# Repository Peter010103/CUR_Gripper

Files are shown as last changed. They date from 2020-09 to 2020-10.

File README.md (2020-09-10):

# CUR_Gripper
Cambridge University Robotics > Robocup Rescue > GripperV4

- URDF file produced using https://github.com/yanshil/Fusion2PyBullet
- Visualisation graphs produced using https://github.com/yanshil/Joint2Graphviz

The Fusion scripts from the above links are in the scripts folder for convenience.

# Hardware Overview
- 6 x ROBOTIS AX-12A actuators used for Gripper, Roll & Yaw Axis & Pitch Axis(?)
- 3D printed in PETG (STL files in [assets](catkin_ws/src/gripperv4/assets))

Follows a common 4-bar linkage (parallelogram) mechanism for gripping action. The wrist axes are designed to be able to rotate a full 360 degrees (must ensure long enough wires are used !)

<p align="center">
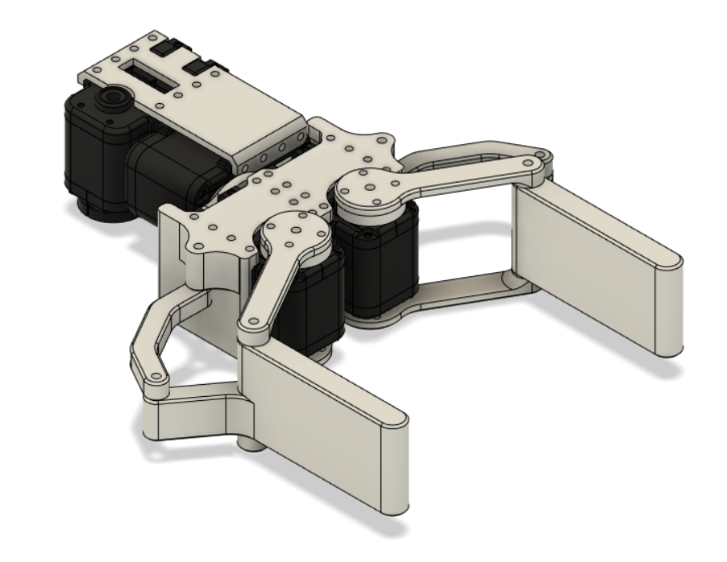
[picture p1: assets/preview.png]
  
</p>

# URDF Layout
<p align="center">
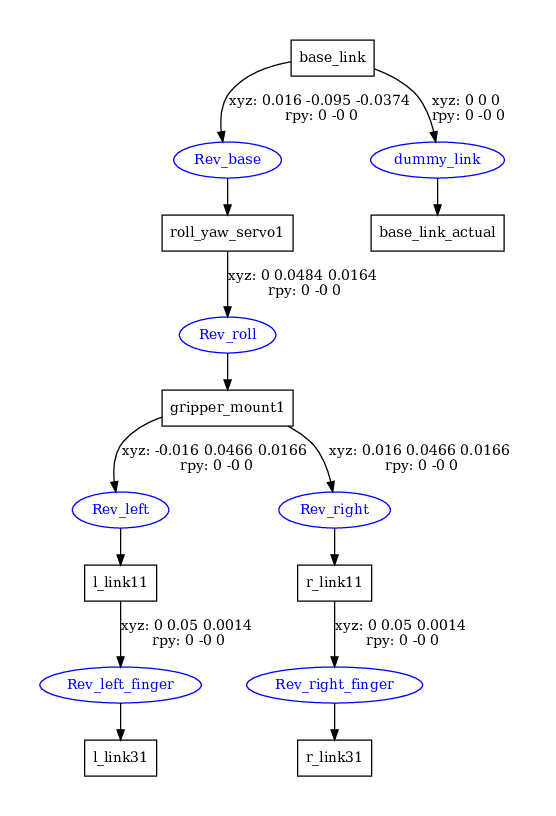
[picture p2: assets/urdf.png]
  
</p>

To conform with the URDF format, some components were removed to make the tree 'open-loop' in RViz. Dependent joints between the servo arm (link1) and the finger (link3) were added ([dependent_joints.yaml](catkin_ws/src/gripperv4/config/dependent_joints.yaml)) instead to mimic the motion of the parallelogram mechanism.

# RViz Simulation
<p align="center">
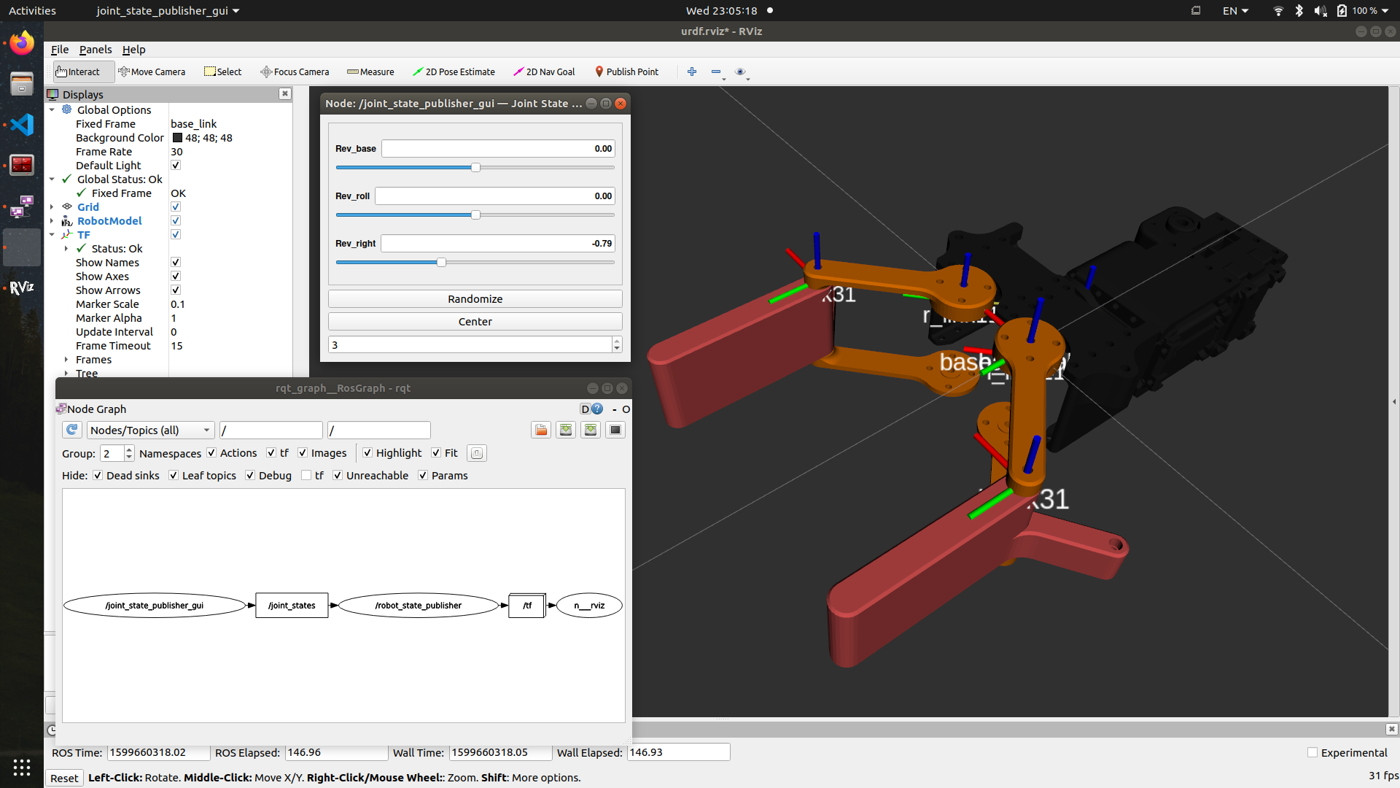
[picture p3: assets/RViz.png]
  
</p>

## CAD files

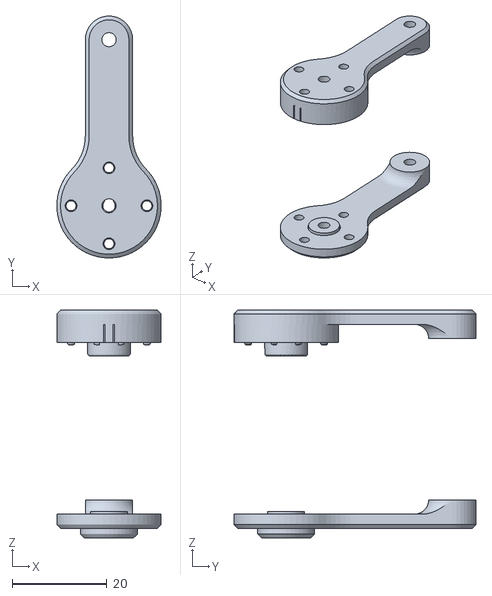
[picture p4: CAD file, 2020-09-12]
assets/gripperv4_urdf/meshes/r_link11.stl
22.0 x 51.0 x 48.0

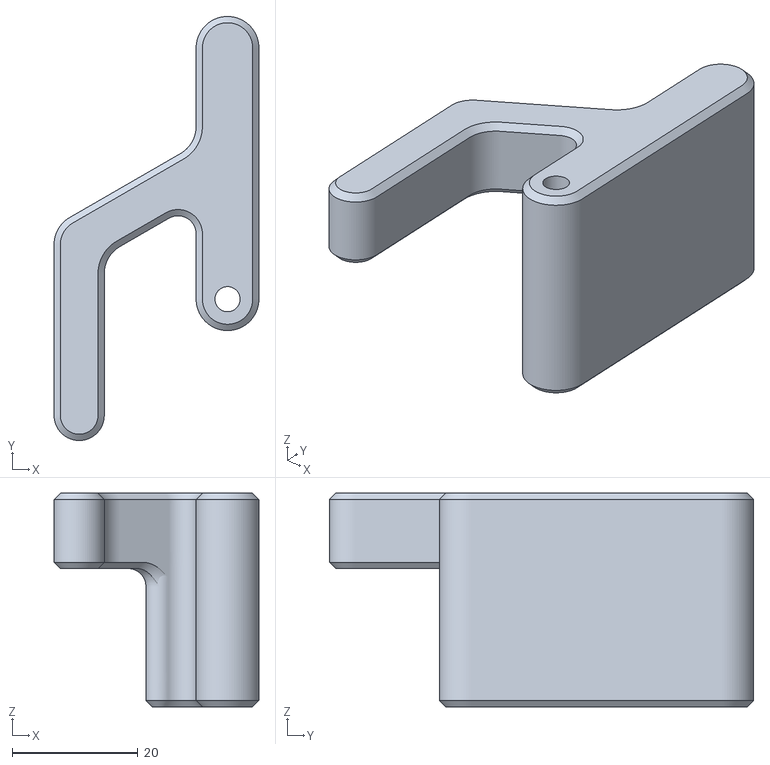
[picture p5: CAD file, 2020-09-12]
assets/STL/l_link3.stl
32.6 x 67.5 x 34.0

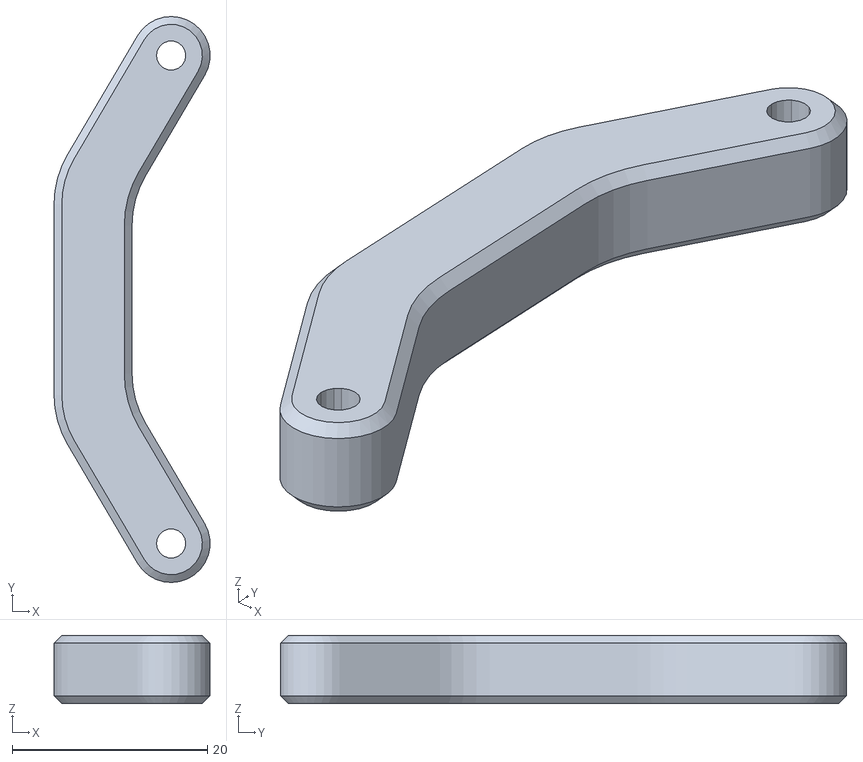
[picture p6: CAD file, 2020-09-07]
gripperv4_description/meshes/L_Link2_1.stl
16.0 x 58.0 x 7.00

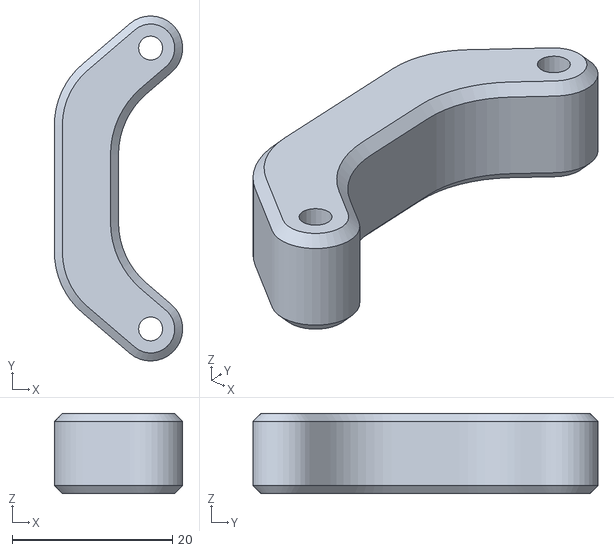
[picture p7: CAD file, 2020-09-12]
assets/gripperv4_urdf/meshes/l_link21.stl
16.0 x 43.0 x 10.0

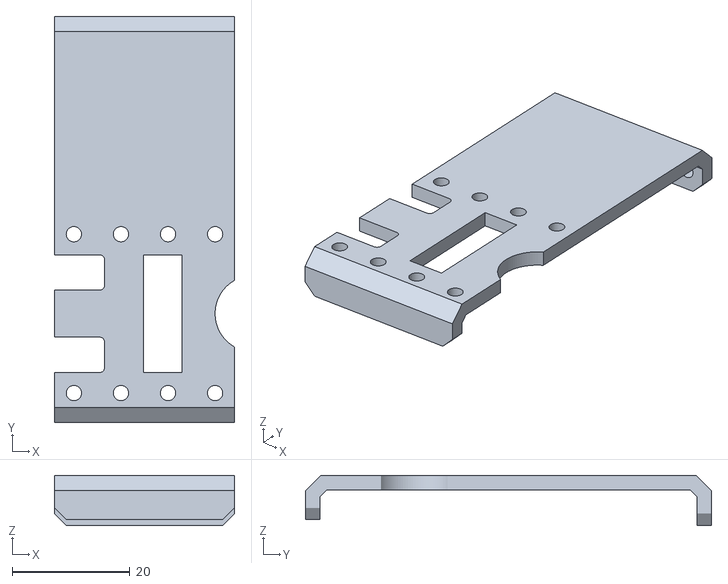
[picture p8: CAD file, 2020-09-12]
assets/STL/roll_yaw_mount1.stl
30.6 x 69.0 x 8.50

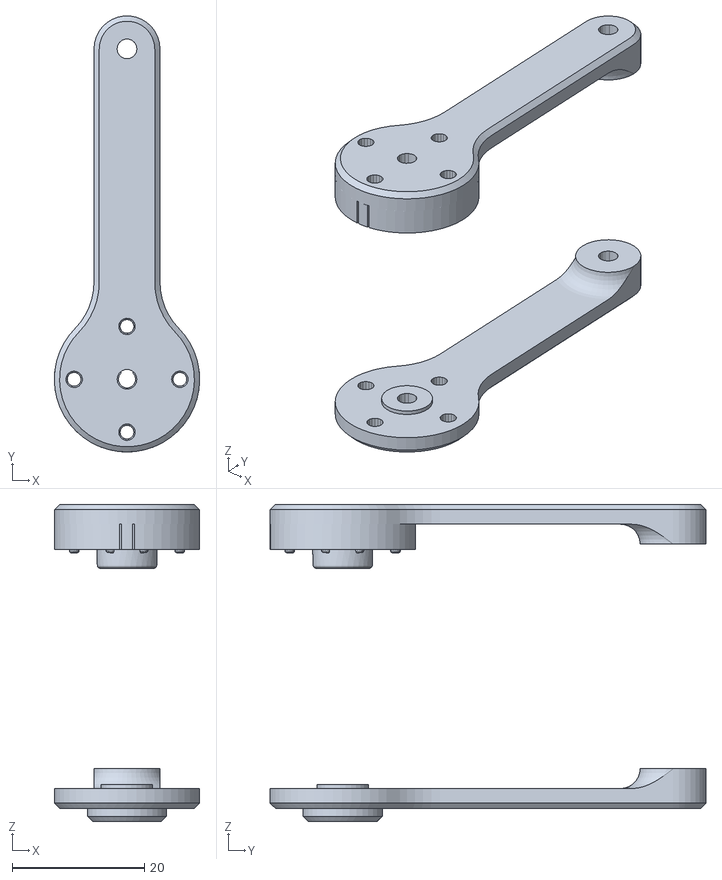
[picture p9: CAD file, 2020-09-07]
gripperv4_description/meshes/R_Link1_1.stl
22.0 x 66.0 x 48.0

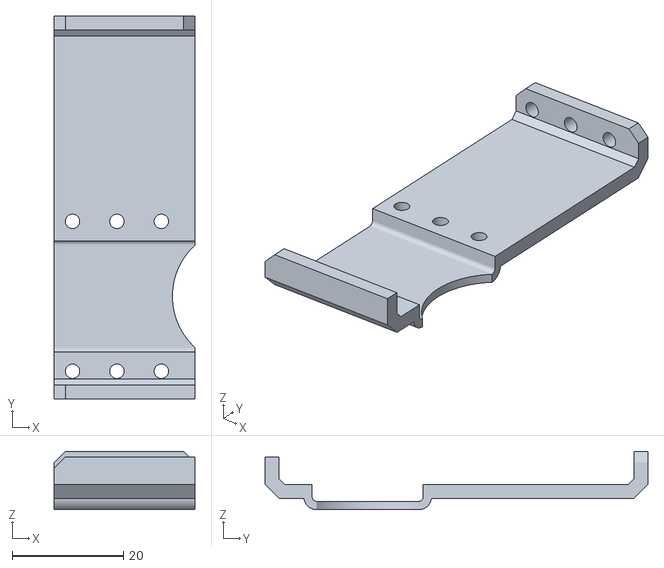
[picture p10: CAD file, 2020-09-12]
assets/STL/roll_yaw_mount2.stl
25.3 x 69.0 x 10.5

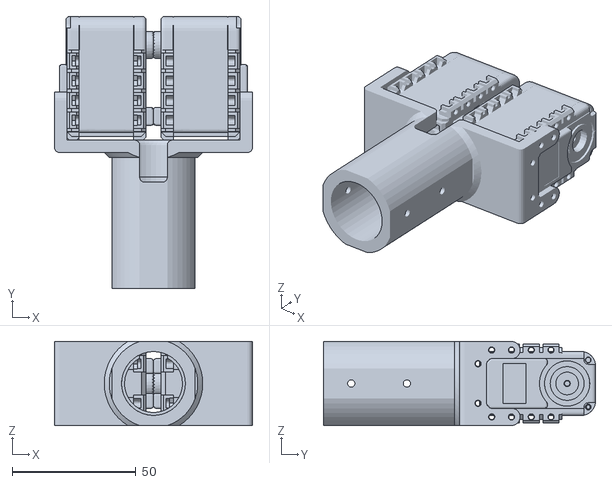
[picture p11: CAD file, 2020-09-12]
catkin_ws/src/gripperv4/assets/base_link.stl
80.0 x 110.0 x 34.0

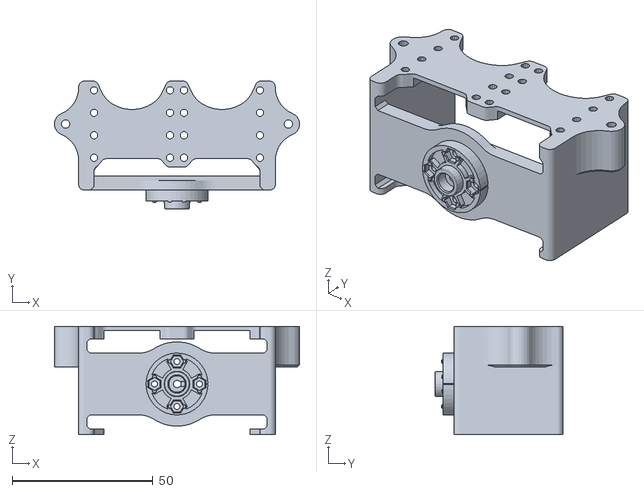
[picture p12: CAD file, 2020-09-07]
gripperv4_description/meshes/Mount1_1.stl
87.2 x 45.5 x 38.5

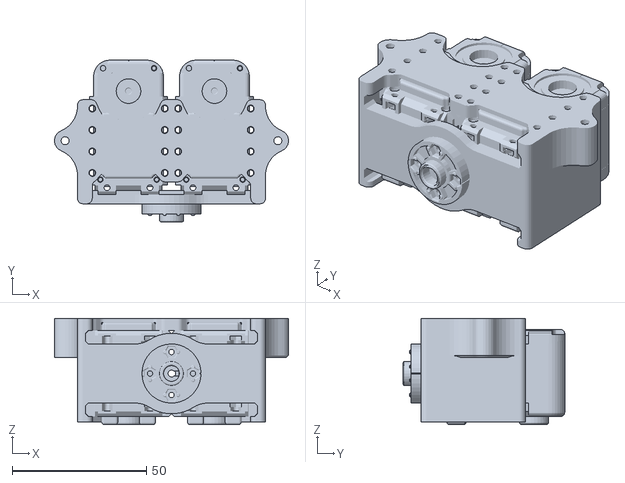
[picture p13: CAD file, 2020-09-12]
catkin_ws/src/gripperv4/assets/gripper_mount1.stl
87.2 x 60.2 x 39.5

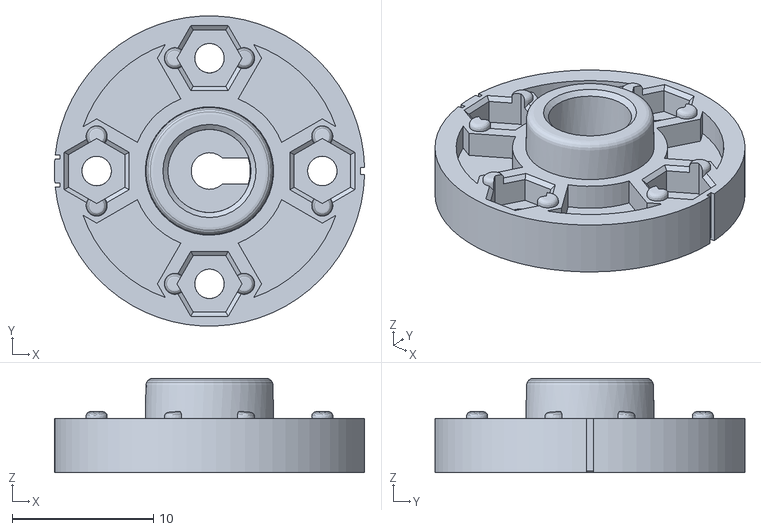
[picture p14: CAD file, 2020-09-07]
gripperv4_description/meshes/base_link.stl
22.0 x 22.0 x 6.70

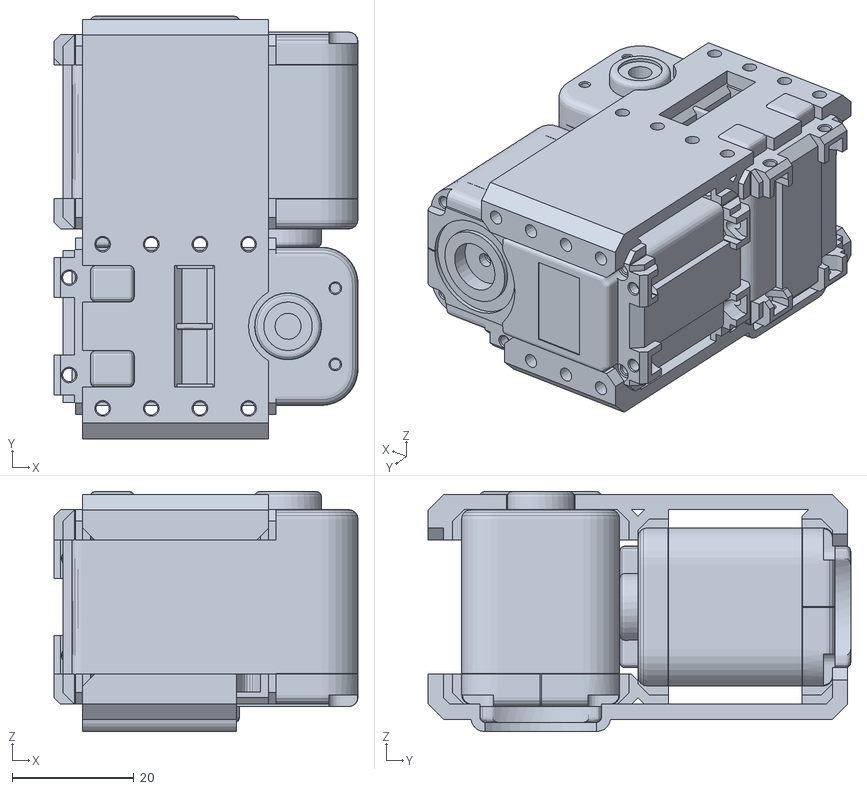
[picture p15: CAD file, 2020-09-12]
assets/gripperv4_urdf/meshes/roll_yaw_servo1.stl
50.0 x 69.5 x 39.5

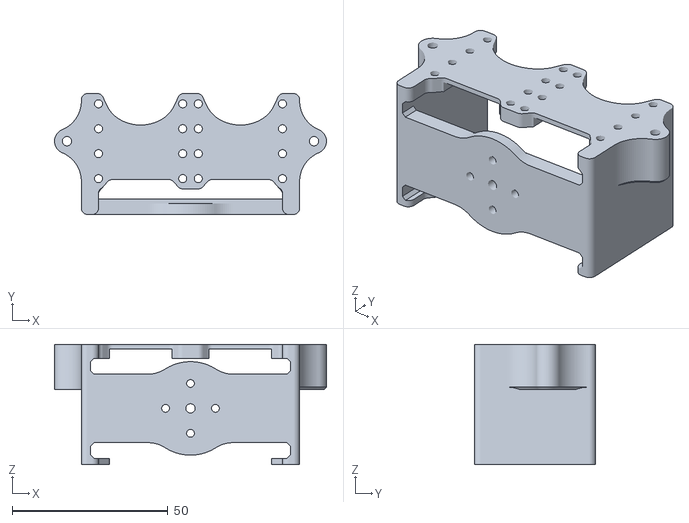
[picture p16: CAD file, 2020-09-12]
assets/STL/gripper_mount.stl
87.2 x 38.8 x 38.5

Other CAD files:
catkin_ws/src/gripperv4/assets/l_link11.stl
assets/gripperv4_urdf/meshes/r_link21.stl
assets/STL/r_link2.stl
archive/gripperv4/meshes/base_link.stl
archive/gripperv4/meshes/gripper_mount1.stl
archive/gripperv4/meshes/l_link11.stl
archive/gripperv4/meshes/l_link31.stl
archive/gripperv4/meshes/l_servo1.stl
archive/gripperv4/meshes/r_link11.stl
archive/gripperv4/meshes/r_link21.stl
archive/gripperv4/meshes/r_link31.stl
archive/gripperv4/meshes/r_servo1.stl
archive/gripperv4/meshes/roll2yaw_mount1.stl
archive/gripperv4/meshes/roll_servo1.stl
archive/gripperv4/meshes/yaw_servo1.stl
archive/gripperv4_description/meshes/L_Body_1.stl
archive/gripperv4_description/meshes/L_Link1_1.stl
archive/gripperv4_description/meshes/L_Link3_1.stl
archive/gripperv4_description/meshes/Mount2_1.stl
archive/gripperv4_description/meshes/R_Body_1.stl
archive/gripperv4_description/meshes/R_Link2_1.stl
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

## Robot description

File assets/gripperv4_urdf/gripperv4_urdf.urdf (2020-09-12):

<?xml version="1.0" ?>
<robot name="gripperv4_urdf">

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

<link name="base_link">
  <inertial>
    <origin rpy="0 0 0" xyz="2.1845298122770527e-09 -0.09133155977238687 0.020875468296511556"/>
    <mass value="0.9490572232520995"/>
    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
  </inertial>
  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
</link>

<link name="pitch_mount1">
  <inertial>
    <origin rpy="0 0 0" xyz="-0.035381834259905855 0.022820220401733052 -0.002066974265373219"/>
    <mass value="0.08039663104912372"/>
    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
  </inertial>
  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
</link>

<link name="roll_yaw_servo1">
  <inertial>
    <origin rpy="0 0 0" xyz="-0.01326814497835662 0.016285248127358473 -0.018675533177308117"/>
    <mass value="0.6469480906726006"/>
    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
  </inertial>
  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
</link>

<link name="gripper_mount1">
  <inertial>
    <origin rpy="0 0 0" xyz="-4.6437802248194846e-05 0.03250667598502349 0.0006919679540483038"/>
    <mass value="0.6706735500880907"/>
    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
  </inertial>
  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
</link>

<link name="r_link11">
  <inertial>
    <origin rpy="0 0 0" xyz="9.352171946239163e-08 0.004350148087522404 -0.003859751771437374"/>
    <mass value="0.01374798583124482"/>
    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
  </inertial>
  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
</link>

<link name="r_finger1">
  <inertial>
    <origin rpy="0 0 0" xyz="0.004967469486381864 0.01646646237182653 -0.015003164576295747"/>
    <mass value="0.023712538812289255"/>
    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
  </inertial>
  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
</link>

<link name="l_link11">
  <inertial>
    <origin rpy="0 0 0" xyz="9.506871556999585e-08 0.004350155042648504 -0.0038597459406704976"/>
    <mass value="0.013747989643093032"/>
    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
  </inertial>
  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
</link>

<link name="l_finger1">
  <inertial>
    <origin rpy="0 0 0" xyz="-0.004967279382909973 0.01646646237182653 -0.015003164576295747"/>
    <mass value="0.023712538812289255"/>
    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
  </inertial>
  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
</link>

<link name="l_link21">
  <inertial>
    <origin rpy="0 0 0" xyz="-0.005348338062402411 0.017499999999999932 -0.004999999999999647"/>
    <mass value="0.00386409068463368"/>
    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
  </inertial>
  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
</link>

<link name="r_link21">
  <inertial>
    <origin rpy="0 0 0" xyz="0.005348528165873591 0.017499999999999932 -0.004999999999999647"/>
    <mass value="0.0038640906846336806"/>
    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
  </inertial>
  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
</link>

<joint name="Rev27" type="continuous">
  <origin rpy="0 0 0" xyz="0.0354 -0.063124 0.021"/>
  <parent link="base_link"/>
  <child link="pitch_mount1"/>
  <axis xyz="1.0 0.0 0.0"/>
</joint>
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

<joint name="Rev28" type="continuous">
  <origin rpy="0 0 0" xyz="-0.035383 0.063124 0.0184"/>
  <parent link="pitch_mount1"/>
  <child link="roll_yaw_servo1"/>
  <axis xyz="0.0 0.0 1.0"/>
</joint>
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

<joint name="Rev29" type="continuous">
  <origin rpy="0 0 0" xyz="0.0 0.0484 -0.0184"/>
  <parent link="roll_yaw_servo1"/>
  <child link="gripper_mount1"/>
  <axis xyz="0.0 1.0 -0.0"/>
</joint>
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

<joint name="Rev30" type="continuous">
  <origin rpy="0 0 0" xyz="0.016 0.0466 0.0164"/>
  <parent link="gripper_mount1"/>
  <child link="r_link11"/>
  <axis xyz="0.0 -0.0 1.0"/>
</joint>
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

<joint name="Rev31" type="continuous">
  <origin rpy="0 0 0" xyz="0.0 0.035 0.0016"/>
  <parent link="r_link11"/>
  <child link="r_finger1"/>
  <axis xyz="0.0 -0.0 1.0"/>
</joint>
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

<joint name="Rev32" type="continuous">
  <origin rpy="0 0 0" xyz="-0.016 0.0466 0.0164"/>
  <parent link="gripper_mount1"/>
  <child link="l_link11"/>
  <axis xyz="0.0 -0.0 1.0"/>
</joint>
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

<joint name="Rev33" type="continuous">
  <origin rpy="0 0 0" xyz="0.0 0.035 0.0016"/>
  <parent link="l_link11"/>
  <child link="l_finger1"/>
  <axis xyz="-0.0 0.0 -1.0"/>
</joint>
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

<joint name="Rev34" type="continuous">
  <origin rpy="0 0 0" xyz="-0.039617 0.0281 0.006"/>
  <parent link="gripper_mount1"/>
  <child link="l_link21"/>
  <axis xyz="-0.0 0.0 -1.0"/>
</joint>
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

<joint name="Rev35" type="continuous">
  <origin rpy="0 0 0" xyz="0.039617 0.0281 0.006"/>
  <parent link="gripper_mount1"/>
  <child link="r_link21"/>
  <axis xyz="0.0 -0.0 1.0"/>
</joint>
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

</robot>

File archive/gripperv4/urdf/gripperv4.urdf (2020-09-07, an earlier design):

<?xml version="1.0" ?>
<robot name="gripperv4">

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

<link name="base_link">
  <inertial>
    <origin rpy="0 0 0" xyz="0.015992436485837883 -0.0949999999742469 -0.040090057637020185"/>
    <mass value="0.009061016616131982"/>
    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
  </inertial>
  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
</link>

<link name="yaw_servo1">
  <inertial>
    <origin rpy="0 0 0" xyz="-0.013167494315320315 -4.684638372969008e-05 0.01584835755541894"/>
    <mass value="0.3184697824599338"/>
    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
  </inertial>
  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
</link>

<link name="roll2yaw_mount1">
  <inertial>
    <origin rpy="0 0 0" xyz="0.014120331710048785 0.03382582487425398 -0.01421655548476504"/>
    <mass value="0.010008525752734407"/>
    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
  </inertial>
  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
</link>

<link name="roll_servo1">
  <inertial>
    <origin rpy="0 0 0" xyz="-0.009967494315320308 -0.014898357555418865 -0.01549684638372982"/>
    <mass value="0.3184697824599338"/>
    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
  </inertial>
  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
</link>

<link name="gripper_mount1">
  <inertial>
    <origin rpy="0 0 0" xyz="-4.055486153327348e-05 0.015016957245028106 0.0033366712510858668"/>
    <mass value="0.03378268770833562"/>
    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
  </inertial>
  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
</link>

<link name="l_servo1">
  <inertial>
    <origin rpy="0 0 0" xyz="0.013453153616270093 0.0013325056846796753 -0.015248357555418993"/>
    <mass value="0.3184697824599338"/>
    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
  </inertial>
  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
</link>

<link name="r_servo1">
  <inertial>
    <origin rpy="0 0 0" xyz="-0.013546846383729903 0.0013325056846796805 -0.015248357555418993"/>
    <mass value="0.3184697824599338"/>
    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
  </inertial>
  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
</link>

<link name="l_link11">
  <inertial>
    <origin rpy="0 0 0" xyz="1.5906387325074444e-11 0.007497428337157438 -0.004836993401442812"/>
    <mass value="0.014672073181914151"/>
    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
  </inertial>
  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
</link>

<link name="l_link31">
  <inertial>
    <origin rpy="0 0 0" xyz="-0.0017956453296221562 0.02496942356962671 -0.018242185156636687"/>
    <mass value="0.027635011745384516"/>
    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
  </inertial>
  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
</link>

<link name="l_link31">
  <inertial>
    <origin rpy="0 0 0" xyz="0.021821354670377845 0.043469423569626714 0.0007578148433633122"/>
    <mass value="0.027635011745384516"/>
    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
  </inertial>
  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
</link>

<link name="l_link21">
  <inertial>
    <origin rpy="0 0 0" xyz="-0.005239897396468952 0.024999999999999953 -0.0034999999999999996"/>
    <mass value="0.0034055466614027626"/>
    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
  </inertial>
  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
</link>

<link name="r_link11">
  <inertial>
    <origin rpy="0 0 0" xyz="-1.4336560688610334e-09 0.007497418801402903 -0.004836999106063676"/>
    <mass value="0.014672069251285016"/>
    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
  </inertial>
  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
</link>

<link name="r_link31">
  <inertial>
    <origin rpy="0 0 0" xyz="0.0017956453296221475 0.024969423569626725 -0.018242185156636687"/>
    <mass value="0.027635011745384488"/>
    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
  </inertial>
  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
</link>

<link name="r_link31">
  <inertial>
    <origin rpy="0 0 0" xyz="-0.02182135467037785 0.04346942356962673 0.0007578148433633122"/>
    <mass value="0.027635011745384488"/>
    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
  </inertial>
  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
</link>

<link name="r_link21">
  <inertial>
    <origin rpy="0 0 0" xyz="0.005239897396468955 0.024999999999999953 -0.0034999999999999996"/>
    <mass value="0.0034055466614027626"/>
    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
  </inertial>
  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
</link>

<joint name="Rev88" type="continuous">
  <origin rpy="0 0 0" xyz="0.016 -0.095 -0.0374"/>
  <parent link="base_link"/>
  <child link="yaw_servo1"/>
  <axis xyz="0.0 0.0 1.0"/>
</joint>
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

<joint name="Rigid89" type="fixed">
  <origin rpy="0 0 0" xyz="-0.0338 -0.01545 0.03185"/>
  <parent link="yaw_servo1"/>
  <child link="roll2yaw_mount1"/>
</joint>

<joint name="Rigid90" type="fixed">
  <origin rpy="0 0 0" xyz="0.0306 0.0629 0.0"/>
  <parent link="roll2yaw_mount1"/>
  <child link="roll_servo1"/>
</joint>

<joint name="Rev91" type="continuous">
  <origin rpy="0 0 0" xyz="0.0032 0.00095 -0.01545"/>
  <parent link="roll_servo1"/>
  <child link="gripper_mount1"/>
  <axis xyz="-0.0 -1.0 0.0"/>
</joint>
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

<joint name="Rigid92" type="fixed">
  <origin rpy="0 0 0" xyz="-0.0295 0.0321 0.016"/>
  <parent link="gripper_mount1"/>
  <child link="l_servo1"/>
</joint>

<joint name="Rigid93" type="fixed">
  <origin rpy="0 0 0" xyz="0.0295 0.0321 0.016"/>
  <parent link="gripper_mount1"/>
  <child link="r_servo1"/>
</joint>

<joint name="Rev94" type="continuous">
  <origin rpy="0 0 0" xyz="0.0135 0.0145 0.0006"/>
  <parent link="l_servo1"/>
  <child link="l_link11"/>
  <axis xyz="0.0 0.0 1.0"/>
</joint>
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

<joint name="Rev95" type="continuous">
  <origin rpy="0 0 0" xyz="-0.023617 0.0315 -0.0176"/>
  <parent link="l_link11"/>
  <child link="l_link31"/>
  <axis xyz="0.0 0.0 1.0"/>
</joint>
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

<joint name="Rev96" type="continuous">
  <origin rpy="0 0 0" xyz="0.0 0.05 -0.007"/>
  <parent link="l_link21"/>
  <child link="l_link31"/>
  <axis xyz="0.0 0.0 -1.0"/>
</joint>
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

<joint name="Rev97" type="continuous">
  <origin rpy="0 0 0" xyz="-0.039617 0.0281 0.006"/>
  <parent link="gripper_mount1"/>
  <child link="l_link21"/>
  <axis xyz="0.0 0.0 -1.0"/>
</joint>
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

<joint name="Rev98" type="continuous">
  <origin rpy="0 0 0" xyz="-0.0135 0.0145 0.0006"/>
  <parent link="r_servo1"/>
  <child link="r_link11"/>
  <axis xyz="0.0 0.0 1.0"/>
</joint>
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

<joint name="Rev99" type="continuous">
  <origin rpy="0 0 0" xyz="0.023617 0.0315 -0.0176"/>
  <parent link="r_link11"/>
  <child link="r_link31"/>
  <axis xyz="0.0 0.0 -1.0"/>
</joint>
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

<joint name="Rev100" type="continuous">
  <origin rpy="0 0 0" xyz="0.0 0.05 -0.007"/>
  <parent link="r_link21"/>
  <child link="r_link31"/>
  <axis xyz="0.0 0.0 1.0"/>
</joint>
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

<joint name="Rev101" type="continuous">
  <origin rpy="0 0 0" xyz="0.039617 0.0281 0.006"/>
  <parent link="gripper_mount1"/>
  <child link="r_link21"/>
  <axis xyz="0.0 0.0 1.0"/>
</joint>
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

</robot>

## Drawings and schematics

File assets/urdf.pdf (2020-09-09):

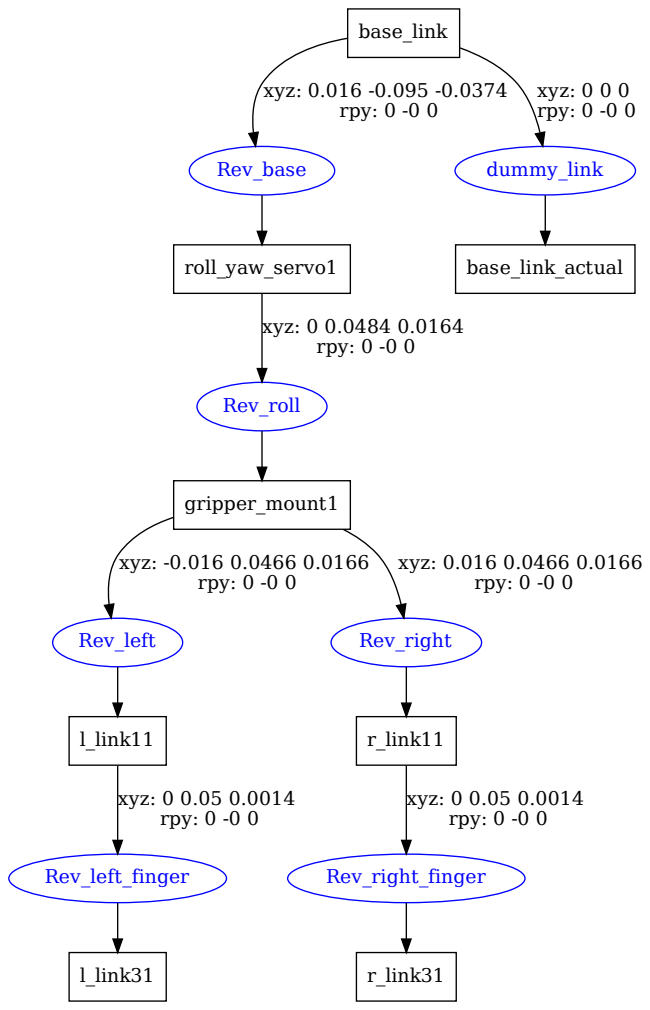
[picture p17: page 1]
base_link; Rev_base; xyz: 0.016 -0.095 -0.0374 rpy: 0 -0 0; dummy_link; xyz: 0 0 0 rpy: 0 -0 0; roll_yaw_servo1; Rev_roll; xyz: 0 0.0484 0.0164 rpy: 0 -0 0; gripper_mount1; Rev_left; xyz: -0.016 0.0466 0.0166 rpy: 0 -0 0; Rev_right; xyz: 0.016 0.0466 0.0166 rpy: 0 -0 0; l_link11; Rev_left_finger; xyz: 0 0.05 0.0014 rpy: 0 -0 0; l_link31; r_link11; Rev_right_finger; r_link31; base_link_actual

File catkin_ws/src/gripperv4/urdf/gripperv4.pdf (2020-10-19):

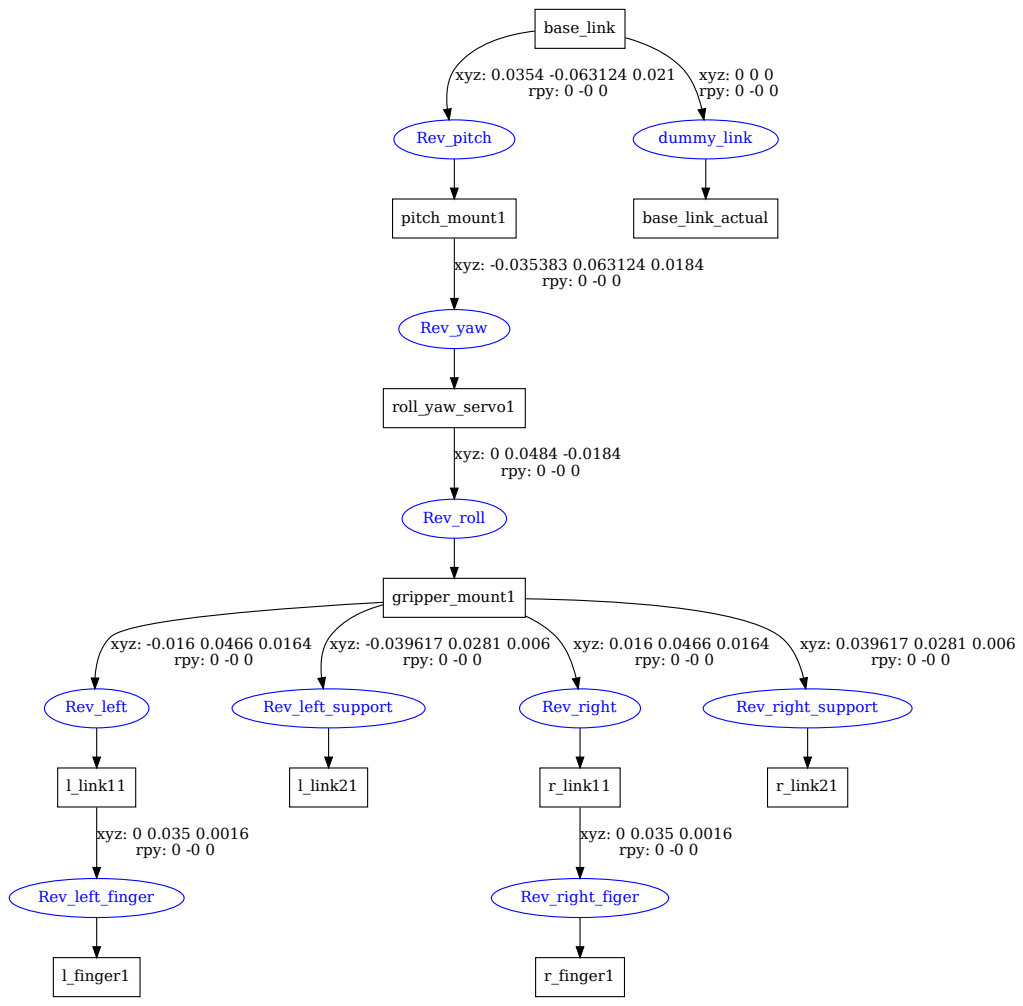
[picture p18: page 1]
base_link; Rev_pitch; xyz: 0.0354 -0.063124 0.021 rpy: 0 -0 0; dummy_link; xyz: 0 0 0 rpy: 0 -0 0; pitch_mount1; Rev_yaw; xyz: -0.035383 0.063124 0.0184 rpy: 0 -0 0; roll_yaw_servo1; Rev_roll; xyz: 0 0.0484 -0.0184 rpy: 0 -0 0; gripper_mount1; Rev_left; xyz: -0.016 0.0466 0.0164 rpy: 0 -0 0; Rev_left_support; xyz: -0.039617 0.0281 0.006 rpy: 0 -0 0; Rev_right; xyz: 0.016 0.0466 0.0164 rpy: 0 -0 0; Rev_right_support; xyz: 0.039617 0.0281 0.006 rpy: 0 -0 0; l_link11; Rev_left_finger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

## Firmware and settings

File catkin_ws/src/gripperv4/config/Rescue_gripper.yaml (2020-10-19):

# You can find control table of Dynamixel on emanual (http://emanual.robotis.com/#control-table)
# Control table item has to be set Camel_Case and not included whitespace
# You are supposed to set at least Dynamixel ID
# This example is compatible with Dynamixel using protocol 2.0
Rev_left:
  ID: 18
  Return_Delay_Time: 0
  CW_Angle_Limit: 202
  CCW_Angle_Limit: 577
Rev_right:
  ID: 16
  Return_Delay_Time: 0
  CW_Angle_Limit: 447
  CCW_Angle_Limit: 822
Rev_roll:
  ID: 15
  Return_Delay_Time: 0
Rev_yaw:
  ID: 17
  Return_Delay_Time: 0

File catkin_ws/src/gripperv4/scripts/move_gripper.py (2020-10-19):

import time
import rospy
from sensor_msgs.msg import JointState
from dynamixel_workbench_msgs.srv import JointCommand, JointCommandRequest
from std_msgs.msg import Header


class OpenManipulatorMove(object):
    def __init__(self):
        rospy.loginfo("OpenManipulatorMove INIT...Please wait.")

        # We subscribe to the joint states to have info of the system

        self.joint_states_topic_name = '/joint_states'
        self._check_join_states_ready()
        sub = rospy.Subscriber(self.joint_states_topic_name, JointState, self.joint_states_callback)


        # We start the Publisher for the positions of the joints
        self.goal_dynamixel_position_publisher = rospy.Publisher('/goal_dynamixel_position',
                                                                    JointState,
                                                                    queue_size=1)

        # Wait for the service client /joint_command to be running
        joint_command_service_name = "/joint_command"
        rospy.wait_for_service(joint_command_service_name)
        # Create the connection to the service
        self.joint_command_service = rospy.ServiceProxy(joint_command_service_name, JointCommand)

        rospy.loginfo("OpenManipulatorMove Ready!")

    def joint_states_callback(self,msg):
        """
        rosmsg show sensor_msgs/JointState
            std_msgs/Header header
              uint32 seq
              time stamp
              string frame_id
            string[] name
            float64[] position
            float64[] velocity
            float64[] effort

        :param msg:
        :return:
        """
        self.joint_states_msg = msg

    def _check_join_states_ready(self):
        self.joint_states_msg = None
        rospy.logdebug("Waiting for "+self.joint_states_topic_name+" to be READY...")
        while self.joint_states_msg is None and not rospy.is_shutdown():
            try:
                self.joint_states_msg = rospy.wait_for_message(self.joint_states_topic_name, JointState, timeout=5.0)
                rospy.logdebug("Current "+self.joint_states_topic_name+" READY=>")

            except:
                rospy.logerr("Current "+self.joint_states_topic_name+" not ready yet, retrying ")

    def move_all_joints(self, position_array):

        rospy.logwarn("move_all_joints STARTED")
        # We check that the position array has the correct number of elements
        number_of_joints = len(self.joint_states_msg.name)

        if len(position_array) == number_of_joints:
            if self.check_gripper_pos_safe(position_array[6]):
                new_joint_position = JointState()

                h = Header()
                h.stamp = rospy.Time.now()  # Note you need to call rospy.init_node() before this will work
                h.frame_id = self.joint_states_msg.header.frame_id

                new_joint_position.header = h
                new_joint_position.name = self.joint_states_msg.name
                new_joint_position.position = position_array

                # These values arent used, so they dont matter really
                new_joint_position.velocity = self.joint_states_msg.velocity
                new_joint_position.effort = self.joint_states_msg.effort

                rospy.logwarn("PUBLISH STARTED")
                self.goal_dynamixel_position_publisher.publish(new_joint_position)
                rospy.logwarn("PUBLISH FINISHED")
            else:
                rospy.logerr("Gripper position NOT valid=" + str(position_array[6]))
        else:
            rospy.logerr("The Array given doesnt have the correct length="+str(number_of_joints))

        rospy.logwarn("move_all_joints FINISHED")


    def move_one_joint(self, joint_id, position, unit="rad"):
        """
        rossrv show dynamixel_workbench_msgs/JointCommand
            string unit
            uint8 id
            float32 goal_position
            ---
            bool result

        :param joint_id:
        :param position:
        :param units:
        :return:
        """
        joint_cmd_req = JointCommandRequest()
        joint_cmd_req.unit = unit
        joint_cmd_req.id = joint_id
        joint_cmd_req.goal_position = position

        if joint_id == 7:
            rospy.logwarn("CHECKING Gripper Value is safe?")
            if self.check_gripper_pos_safe(position):

                # Send through the connection the name of the object to be deleted by the service
                result = self.joint_command_service(joint_cmd_req)
                rospy.logwarn("move_one_joint went ok?="+str(result))
            else:
                rospy.logwarn("Gripper Value Not safe=" + str(position))
        else:
            # Send through the connection the name of the object to be deleted by the service
            result = self.joint_command_service(joint_cmd_req)
            rospy.logwarn("move_one_joint went ok?=" + str(result))

    def get_joint_names(self):
        return self.joint_states_msg.name


    def check_gripper_pos_safe(self, gripper_value):
        """
        We need to check that the gripper pos is -1.0 > position[6] > -3.14
        Otherwise it gets jammed
        :param gripper_value:
        :return:
        """
        return (-0.5 > gripper_value > -2.0)

def movement_sequence_test():

    openman_obj = OpenManipulatorMove()

    # NOD
    joint_position_home = [0.08743690699338913, 1.0385050773620605, -2.345456600189209, -0.016873789951205254,
                           -1.4818254709243774, 0.0015339808305725455, -1.0599807500839233]
    joint_position1 = [0.8897088766098022, 0.6059224009513855, -1.4419419765472412, -0.016873789951205254,
                       -1.4818254709243774, 0.0015339808305725455, -1.0599807500839233]
    joint_position2 = [0.8912428617477417, 0.5859806537628174, -1.6060779094696045, -0.016873789951205254,
                       -0.8191457390785217, 0.004601942375302315, -1.0599807500839233]
    joint_position3 = [0.8897088766098022, 0.6028544902801514, -1.8745245933532715, -0.015339808538556099,
                       0.5292233824729919, 0.003067961661145091, -1.0599807500839233]


    # SAY NO
    joint_left = [0.44332045316696167, 1.0630487203598022, -2.345456600189209, 0.5568350553512573, -1.483359456062317,
                  0.004601942375302315, -1.0599807500839233]
    joint_right = [-0.20862139761447906, 1.0906603336334229, -2.3071072101593018, -0.6488738656044006,
                   -1.483359456062317, -0.4417864680290222, -1.0599807500839233]
    joint_middle = [0.0076699042692780495, 1.1274758577346802, -2.325515031814575, 0.3344078063964844,
                    -1.4848934412002563, 0.46172821521759033, -1.0599807500839233]

    # Pendulum
    pend_left = [0.46479618549346924, 0.13345633447170258, -1.728796362876892, 1.5907381772994995, -1.6797089576721191, 0.004601942375302315, -1.0799225568771362]
    pend_middle = [0.39269909262657166, 0.1595340073108673, -2.0984857082366943, -0.09817477315664291, -1.0615147352218628, -0.0015339808305725455, -1.0799225568771362]
    pend_right = [0.006135923322290182, 0.42337870597839355, -1.8806605339050293, -1.306951642036438, -1.0661166906356812, -0.004601942375302315, -1.0799225568771362]


    joint_position_sequence_nod = []
    joint_position_sequence_nod.append(joint_position_home)
    joint_position_sequence_nod.append(joint_position1)
    joint_position_sequence_nod.append(joint_position2)
    joint_position_sequence_nod.append(joint_position3)
    joint_position_sequence_nod.append(joint_position2)
    joint_position_sequence_nod.append(joint_position3)
    joint_position_sequence_nod.append(joint_position1)
    joint_position_sequence_nod.append(joint_position_home)

    joint_position_sequence_say_no = []
    joint_position_sequence_nod.append(joint_position_home)
    joint_position_sequence_nod.append(joint_left)
    joint_position_sequence_nod.append(joint_middle)
    joint_position_sequence_nod.append(joint_right)
    joint_position_sequence_nod.append(joint_left)
    joint_position_sequence_nod.append(joint_middle)
    joint_position_sequence_nod.append(joint_right)
    joint_position_sequence_nod.append(joint_left)
    joint_position_sequence_nod.append(joint_right)
    joint_position_sequence_nod.append(joint_left)
    joint_position_sequence_nod.append(joint_position_home)


    joint_position_sequence_say_pendulum = []
    joint_position_sequence_say_pendulum.append(joint_position_home)
    joint_position_sequence_say_pendulum.append(pend_left)
    joint_position_sequence_say_pendulum.append(pend_middle)
    joint_position_sequence_say_pendulum.append(pend_right)
    joint_position_sequence_say_pendulum.append(pend_left)
    joint_position_sequence_say_pendulum.append(pend_middle)
    joint_position_sequence_say_pendulum.append(pend_right)
    joint_position_sequence_say_pendulum.append(pend_left)
    joint_position_sequence_say_pendulum.append(pend_middle)
    joint_position_sequence_say_pendulum.append(pend_right)
    joint_position_sequence_say_pendulum.append(joint_position_home)



    for joint_position_array in joint_position_sequence_nod:
        openman_obj.move_all_joints(joint_position_array)
        time.sleep(0.5)

    for joint_position_array in joint_position_sequence_say_no:
        openman_obj.move_all_joints(joint_position_array)
        time.sleep(0.2)

    for joint_position_array in joint_position_sequence_say_pendulum:
        openman_obj.move_all_joints(joint_position_array)
        time.sleep(0.5)

def move_joints_test():
    """
    This is for Geting the positions of the joints without testing them
    live, which is quite dangerous!
    :return:
    """
    openman_obj = OpenManipulatorMove()
    joint_names = openman_obj.get_joint_names()
    rospy.logwarn("Starting Moving Joints GUI...")
    while not rospy.is_shutdown():
        rospy.logwarn("#######"+str(joint_names)+"#####")
        joint_id = int(raw_input("Joint ID="))
        joint_position = float(raw_input("Joint Position Radians="))
        openman_obj.move_one_joint(joint_id, joint_position, unit="rad")
        rospy.logwarn("####################")


if __name__ == "__main__":
    rospy.init_node('move_openmanipulator_node', log_level=rospy.WARN)
    #move_joints_test()
    movement_sequence_test()

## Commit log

2020-09-07 Added URDF and launch files
    [GripperV4_URDF.xacro, L_Body_1.stl, L_Link1_1.stl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]
2020-09-07 Successfully created URDF with all components
    [GripperV4_URDF.xacro, L_Body_1.stl, L_Link1_1.stl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]
2020-09-07 Added catkin workspace // Need to fix problem with 4 bar linkages and RViz
    [L_Body_1.stl, L_Link1_1.stl, L_Link2_1.stl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]
2020-09-08 Setup ros code for visualising model and setting joints. Tweaked model to remove closed loops.
    [gripperv4.urdf]
2020-09-09 Added necessary STLs for new URDF
    [gripper_mount1.stl, roll_yaw_servo1.stl]
2020-09-09 Added new URDF with hopefully correct joints
    [gripperv4.urdf, gripperv4_4.f3d]
2020-09-09 Visualisation successful in RViz with updated joints
    [gripper_mount1.stl, gripperv4.urdf]
2020-09-09 Added URDF preview image
    [gripperv4_3.f3d]
2020-09-12 Added URDF with pitch axis and arm_mount
    [base_link.stl, gripper_mount.stl, gripper_mount1.stl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]
2020-10-19 Updated with new design and added code to control DYNAMIXELs individually
    [base_link.stl, gripper_controller.yaml, gripper_mount1.stl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]
